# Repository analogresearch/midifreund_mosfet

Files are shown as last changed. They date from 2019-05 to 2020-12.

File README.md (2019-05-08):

# midifreund_mosfet

DC IN: 9..28 V 

Ansteuerung durch MIDI note 36 (C2) und eine Oktave dur hoch bis C3.
also:
36 38 40 41 43 45 47 48

MIDI channel und Programm werden binär über DIP Schalter gewählt.

MIDI: Ausnahme DIP Schalter 0000 = MIDI channel 16!

Programme:  
(0) note on schaltet ein, note off schaltet aus.  

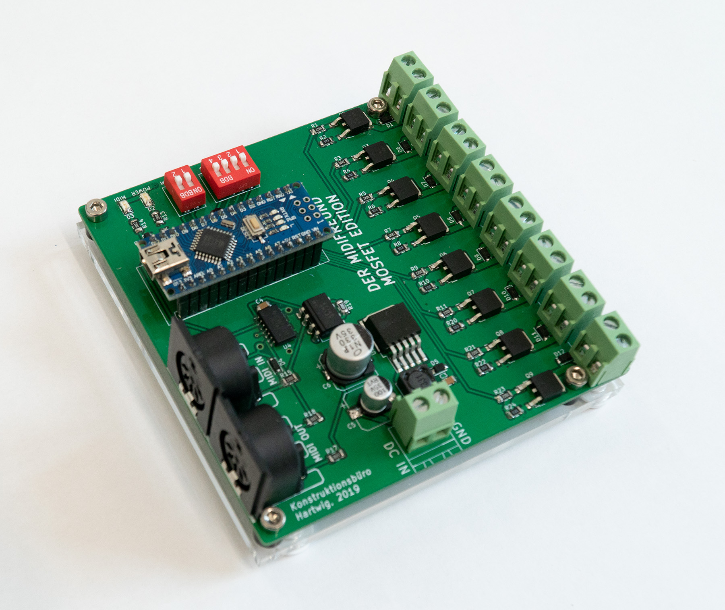
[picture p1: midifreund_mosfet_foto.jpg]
ein Bild ein Foto


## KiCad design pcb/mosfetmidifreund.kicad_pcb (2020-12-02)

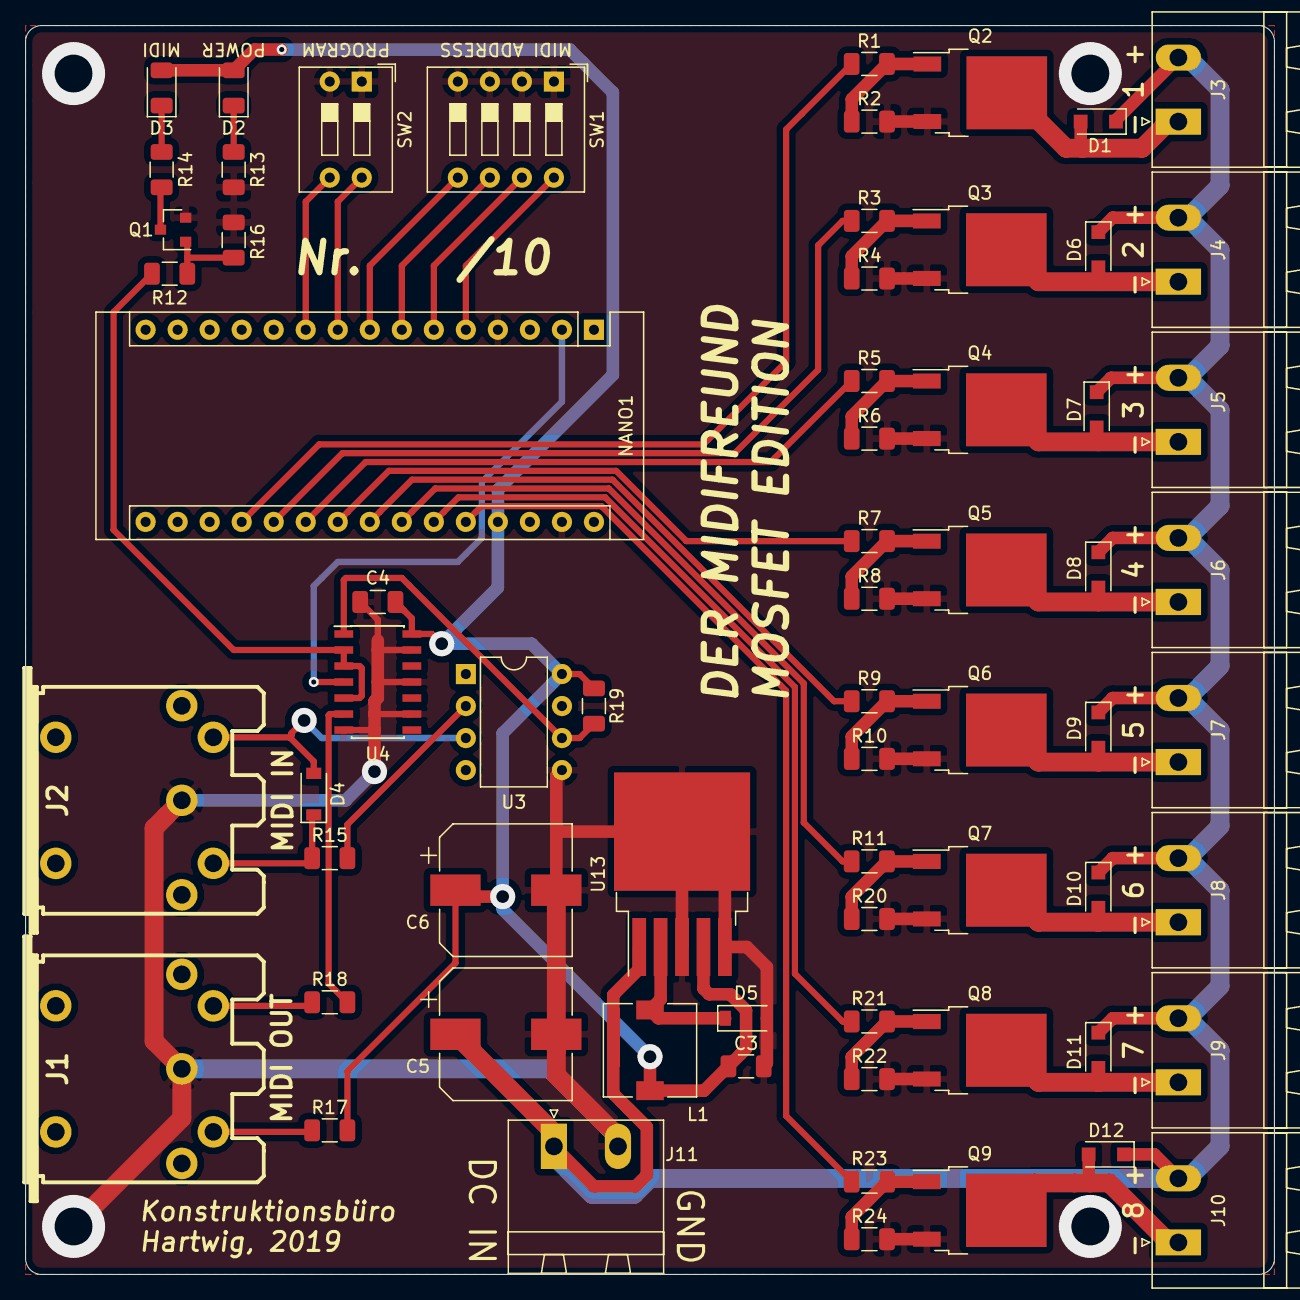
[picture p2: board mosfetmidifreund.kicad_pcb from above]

Board: 2 copper layers, 99.1 x 99.1 mm, 67 parts (0 on the bottom side), 47 nets.

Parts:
C3, C4: 100n; C_1206_3216Metric
C5, C6: 330uF; CP_Elec_10x10
D1, D6, D7, D8, D9, D10, D11, D12: 1N4001; D_SOD-123F
D2: POWER; LED_1206_3216Metric
D3: MIDI; LED_1206_3216Metric
D4: 1N4148; D_SOD-123
D5: 1N5819; D_SOD-123
J1: MIDI OUT; MIDI_DIN5
J2: MIDI IN; MIDI_DIN5
J3, J4, J5, J6, J7, J8, J9, J10, J11: Conn_01x02; PhoenixContact_MSTBA_2,5_2-G-5,08_1x02_P5.08mm_Horizontal
L1: 330uH; L_7.3x7.3_H3.5
NANO1: Arduino_Nano_v3.x; Arduino_Nano
Q1: BSS138; SOT-23
Q2, Q3, Q4, Q5, Q6, Q7, Q8, Q9: IRLR7843; TO-252-2
R1, R3, R5, R7, R9, R11, R13, R14, R15, R17, R18, R21, R23: 220; R_1206_3216Metric
R2, R4, R6, R8, R10, R20, R22, R24: 10k; R_1206_3216Metric
R12: 470; R_1206_3216Metric
R16: 100k; R_1206_3216Metric
R19: 280; R_1206_3216Metric
SW1: SW_DIP_x04; SW_DIP_SPSTx04_Slide_9.78x12.34mm_W7.62mm_P2.54mm
SW2: SW_DIP_x02; SW_DIP_SPSTx02_Slide_9.78x7.26mm_W7.62mm_P2.54mm
U3: 6N137; DIP-8_W7.62mm
U4: 74LS14; SOIC-14_3.9x8.7mm_P1.27mm
U13: LM2575-5.0BU; TO-263-5_TabPin3

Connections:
+5V: C3.1, C4.1, C6.1, D2.2, D3.2, L1.2, NANO1.27, R17.2, R19.1, U3.8, U4.14, U13.4
GND: C3.2, C4.2, C5.2, C6.2, D5.2, J1.2, J2.2, J11.2, NANO1.4, NANO1.29, Q1.2, Q2.3, Q3.3, Q4.3, Q5.3, Q6.3, Q7.3, Q8.3, Q9.3, R2.2, R4.2, R6.2, R8.2, R10.2, R13.1, R16.2, R20.2, R22.2, R24.2, SW1.1, SW1.2, SW1.3, SW1.4, SW2.1, SW2.2, U3.5, U4.7, U4.9, U4.11, U4.13, U13.3, U13.5
unnamed: D1.2, J3.1, Q2.2
unnamed: D2.1, R13.2
unnamed: D3.1, R14.1
unnamed: D4.1, J2.4, R15.1
unnamed: D4.2, J2.5, U3.3
unnamed: D5.1, L1.1, U13.2
unnamed: D6.2, J4.1, Q3.2
unnamed: D7.2, J5.1, Q4.2
unnamed: D8.2, J6.1, Q5.2
unnamed: D9.2, J7.1, Q6.2
unnamed: D10.2, J8.1, Q7.2
unnamed: D11.2, J9.1, Q8.2
unnamed: D12.2, J10.1, Q9.2
unnamed: J1.4, R17.1
unnamed: J1.5, R18.1
unnamed: NANO1.2, U4.4
unnamed: NANO1.5, SW1.8
unnamed: NANO1.6, SW1.7
unnamed: NANO1.7, SW1.6
unnamed: NANO1.8, SW1.5
unnamed: NANO1.9, SW2.4
unnamed: NANO1.10, SW2.3
unnamed: NANO1.19, R1.1
unnamed: NANO1.20, R3.1
unnamed: NANO1.21, R5.1
unnamed: NANO1.22, R7.1
unnamed: NANO1.23, R9.1
unnamed: NANO1.24, R11.1
unnamed: NANO1.25, R21.1
unnamed: NANO1.26, R23.1
unnamed: Q1.1, R12.2, R16.1
unnamed: Q1.3, R14.2
unnamed: Q2.1, R1.2, R2.1
unnamed: Q3.1, R3.2, R4.1
unnamed: Q4.1, R5.2, R6.1
unnamed: Q5.1, R7.2, R8.1
unnamed: Q6.1, R9.2, R10.1
unnamed: Q7.1, R11.2, R20.1
unnamed: Q8.1, R21.2, R22.1
unnamed: Q9.1, R23.2, R24.1
unnamed: R12.1, U4.2, U4.3, U4.5
unnamed: R15.2, U3.2
unnamed: R18.2, U4.6
unnamed: R19.2, U3.6, U4.1
VDD: C5.1, D1.1, D6.1, D7.1, D8.1, D9.1, D10.1, D11.1, D12.1, J3.2, J4.2, J5.2, J6.2, J7.2, J8.2, J9.2, J10.2, J11.1, U13.1

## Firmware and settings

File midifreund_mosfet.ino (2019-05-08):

#include <MIDI.h>

MIDI_CREATE_DEFAULT_INSTANCE()

byte midi_channel;
byte program;

void handler_note_on(byte channel, byte note, byte velocity)
{
  digitalWrite(13, HIGH);
  switch (note) {
    case 36:  //C2
      digitalWrite(A0, HIGH);
      break;
    case 38:
      digitalWrite(A1, HIGH);
      break;
    case 40:
      digitalWrite(A2, HIGH);
      break;
    case 41:
      digitalWrite(A3, HIGH);
      break;
    case 43:
      digitalWrite(A4, HIGH);
      break;
    case 45:
      digitalWrite(A5, HIGH);
      break;
    case 47:
      digitalWrite(9, HIGH);
      break;
    case 48:
      digitalWrite(8, HIGH);
      break;
  }
}

void handler_note_off(byte channel, byte note, byte velocity)
{
  digitalWrite(13, LOW);
  switch (note) {
    case 36:  //C2
      digitalWrite(A0, LOW);
      break;
    case 38:
      digitalWrite(A1, LOW);
      break;
    case 40:
      digitalWrite(A2, LOW);
      break;
    case 41:
      digitalWrite(A3, LOW);
      break;
    case 43:
      digitalWrite(A4, LOW);
      break;
    case 45:
      digitalWrite(A5, LOW);
      break;
    case 47:
      digitalWrite(9, LOW);
      break;
    case 48:
      digitalWrite(8, LOW);
      break;
  }
}

void set_address() { // MIDI Schalter auslesen
  midi_channel = !digitalRead(2) + (!digitalRead(3) << 1) + (!digitalRead(4) << 2 ) + (!digitalRead(5) << 3);
  if (midi_channel == 0) midi_channel = 16;
}

void set_program() { // Programmschalter auslesen
  program = !digitalRead(6) + (!digitalRead(7) << 1);
}

void setup() {

  pinMode(13, OUTPUT);
  pinMode(2, INPUT_PULLUP);
  pinMode(3, INPUT_PULLUP);
  pinMode(4, INPUT_PULLUP);
  pinMode(5, INPUT_PULLUP);
  pinMode(6, INPUT_PULLUP);
  pinMode(7, INPUT_PULLUP);

  pinMode(A0, OUTPUT);
  pinMode(A1, OUTPUT);
  pinMode(A2, OUTPUT);
  pinMode(A3, OUTPUT);
  pinMode(A4, OUTPUT);
  pinMode(A5, OUTPUT);

  pinMode(A6, INPUT);
  pinMode(A7, INPUT);
  pinMode(9, OUTPUT);
  pinMode(8, OUTPUT);

  set_address();
  set_program();

  MIDI.setHandleNoteOn(handler_note_on);
  MIDI.setHandleNoteOff(handler_note_off);
  MIDI.begin(midi_channel);
}

void loop() {
  MIDI.read();
}
